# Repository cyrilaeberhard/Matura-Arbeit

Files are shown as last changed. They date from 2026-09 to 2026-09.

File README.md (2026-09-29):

<div align="center">

# Kamerabasierte Steuerung einer anthropomorphen Roboterhand

**Maturaarbeit 2026 · Cyril Aeberhard**

Eine 3D-gedruckte Roboterhand, die menschliche Fingerbewegungen in Echtzeit nachbildet –
gesteuert allein über eine Laptopkamera, ohne Handschuh und ohne Sensoren am Körper.







</div>

---

## Voraussetzungen

- Laptop mit Python 3 und Kamera
- ESP32 mit MicroPython
- Roboterhand mit 6 Servos (MG90S)

## 3D-Druck

Die Teile der Hand liegen als 3MF-Dateien im Ordner [`3d/`](3d):

| Datei | Teil |
|---|---|
| `finger.3mf` | Finger mit Fingergliedern |
| `handgeruest.3mf` | Handgerüst |
| `servo-aufsatz.3mf` | Aufsatz für die Servos |
| `kabelhalter.3mf` | Kabelhalter |
| `verbindungsstuecke_14-10-6mm.3mf` | Verbindungsstücke in 14, 10 und 6 mm Länge, mit denen die Finger zusammengesetzt werden |

Gedruckt aus ABS+ (Prototypen aus PLA).

## Installation

```bash
python3 -m venv .venv
source .venv/bin/activate
pip install -r requirements.txt
```

> MediaPipe ist auf Version 1.0.0 festgelegt, weil 1.0.1 unter macOS beim Start abstürzt.

## ESP32 einrichten

`recive.py` wird auf dem ESP32 als `main.py` gespeichert und startet so nach dem Einschalten
automatisch:

```bash
mpremote cp robot_hand/config.py :config.py
mpremote cp robot_hand/recive.py :main.py
```

## Einstellungen

In [`robot_hand/config.py`](robot_hand/config.py) an den eigenen Computer anpassen:

| Einstellung | Bedeutung |
|---|---|
| `MODELL_PFAD` | Pfad zu `hand_landmarker.task` |
| `SERIAL_PORT` | USB-Anschluss des ESP32, z. B. `/dev/cu.usbserial-…` |
| `KAMERA_INDEX` | Nummer der Kamera (meist `0` oder `1`) |

## Starten

```bash
python3 robot_hand/main.py
```

Beenden mit `q`.

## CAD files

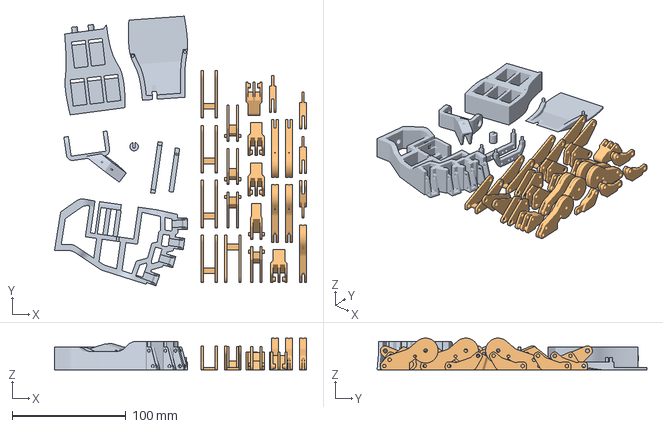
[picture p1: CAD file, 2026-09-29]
3d/finger.3mf
221.8 x 237.3 x 28.0 mm
hand gerüst final
Assembly

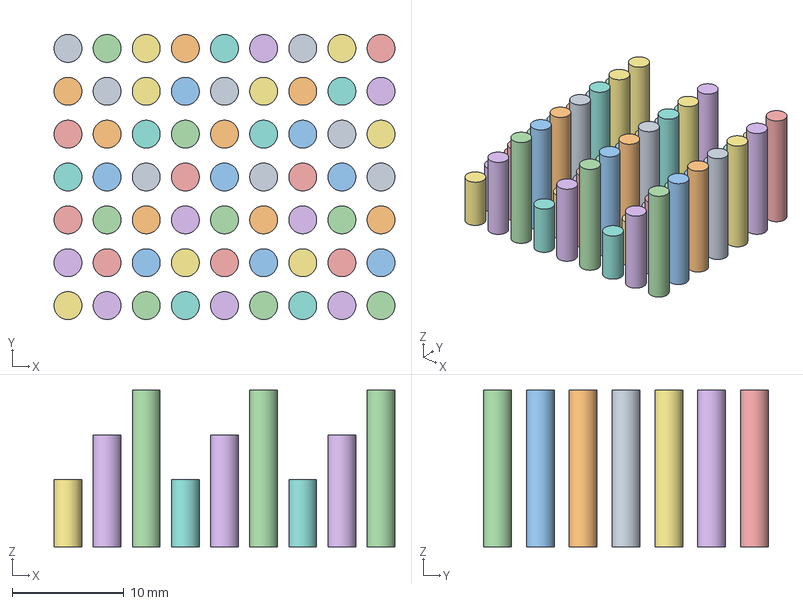
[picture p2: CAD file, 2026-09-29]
3d/verbindungsstuecke_14-10-6mm.3mf
30.5 x 25.5 x 14.0 mm
Körper1
Körper10
Körper11
Körper12
Körper13
Körper14
Körper15
Körper16
Körper17
Körper18
Körper19
Körper2
Körper20
Körper21
Körper22
Körper23
Körper24
Körper25
Körper26
Körper27
Körper28
Körper29
Körper3
Körper30
Körper31
Körper32
Körper33
Körper34
Körper35
Körper36
Körper37
Körper38
Körper39
Körper4
Körper40
Körper41
Körper42
Körper43
Körper44
Körper45
Körper46
Körper47
Körper48
Körper49
Körper5
Körper50
Körper51
Körper52
Körper53
Körper54
Körper55
Körper56
Körper57
Körper58
Körper59
Körper6
Körper60
Körper61
Körper62
Körper63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

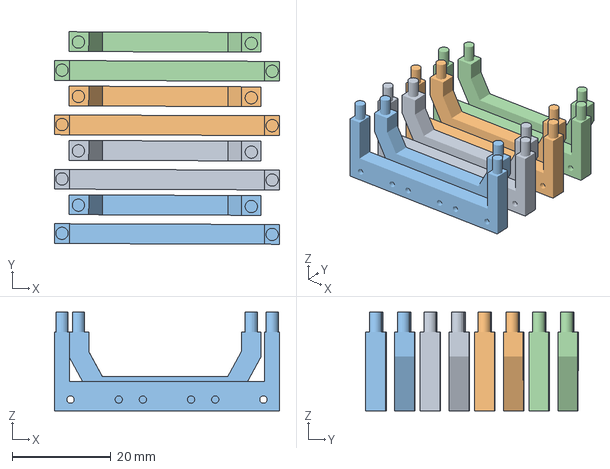
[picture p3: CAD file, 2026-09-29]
3d/handgeruest.3mf
45.5 x 43.0 x 20.0 mm
hand gerüst final x 4

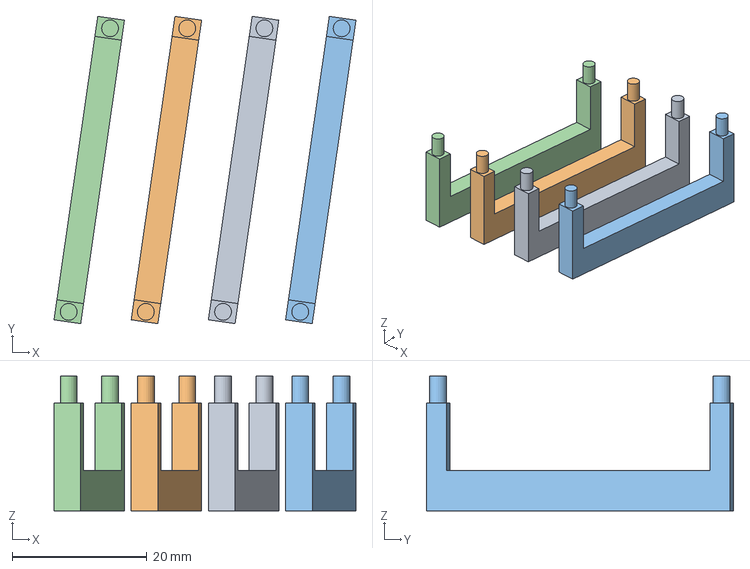
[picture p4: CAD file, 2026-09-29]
3d/kabelhalter.3mf
44.8 x 45.6 x 20.0 mm
Körper1 x 4

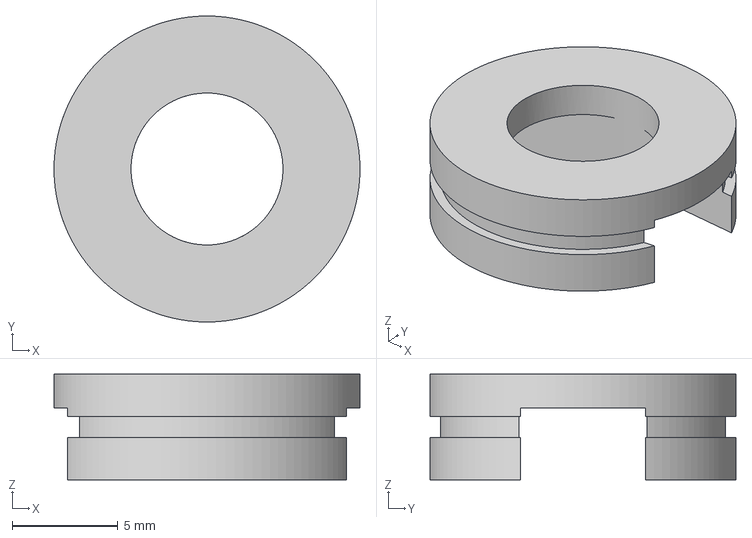
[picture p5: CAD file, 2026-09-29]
3d/servo-aufsatz.3mf
14.5 x 14.5 x 5.00 mm

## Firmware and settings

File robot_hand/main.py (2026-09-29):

# Steuert den gesamten Ablauf: Hand erkennen -> Winkel/PWM berechnen -> senden.

import cv2

import config
import hand_tracking
import calculate
import send


def main(show_camera=True):
    kamera = hand_tracking.kamera_oeffnen()
    letzte_winkel = list(config.START_WINKEL)

    try:
        while True:
            erfolgreich, kamerabild_bgr = kamera.read()
            if not erfolgreich:
                break

            # Spiegeln VOR der Erkennung, damit Landmarks und Text zur
            # gespiegelten Selfie-Ansicht passen (sonst wird auch der Text
            # spiegelverkehrt dargestellt).
            kamerabild_bgr = cv2.flip(kamerabild_bgr, 1)

            kamerabild_rgb, erkennergebnis = hand_tracking.hand_erkennen(kamerabild_bgr)

            if erkennergebnis and erkennergebnis.hand_landmarks:
                hand = erkennergebnis.hand_landmarks[0]
                neue_winkel = calculate.finger_winkel_berechnen(hand)
                letzte_winkel = calculate.glaetten(letzte_winkel, neue_winkel)

            duty_liste = calculate.winkel_liste_zu_duty_liste(letzte_winkel)
            send.duty_werte_senden(duty_liste)

            if show_camera:
                bild_mit_fingern = hand_tracking.zeichne_punkte_und_text(
                    kamerabild_rgb, erkennergebnis, letzte_winkel
                )
                bild_mit_fingern_bgr = cv2.cvtColor(bild_mit_fingern, cv2.COLOR_RGB2BGR)
                cv2.imshow("Handerkennung", bild_mit_fingern_bgr)

                if cv2.waitKey(1) & 0xFF == ord("q"):
                    break

    finally:
        kamera.release()
        cv2.destroyAllWindows()
        send.schliessen()


if __name__ == "__main__":
    main(show_camera=True)

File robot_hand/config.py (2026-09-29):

# Zentrale Einstellungen für die Handerkennung -> Servo-Steuerung.
# Diese Datei wird sowohl von den Host-Skripten (main.py, hand_tracking.py, ...)
# als auch vom ESP32 (recive.py, per mpremote/ampy hochgeladen) eingelesen.

# --- Kamera / MediaPipe ---
KAMERA_INDEX = 1
MODELL_PFAD = "/Users/cyrilaeberhard/local python/python/Maturaarbeit/hand_landmarker.task"
ANZAHL_HAENDE = 1

# --- Serielle Verbindung (Host <-> ESP32) ---
SERIAL_PORT = "/dev/cu.usbserial-11230"
BAUDRATE = 115200
SERIAL_TIMEOUT = 1

# --- Servo-Pins am ESP32 ---
# Reihenfolge: Daumen, Zeige, Mittel, Ring, Klein, Daumen-CMC (Abspreizung)
# TODO: Pin für den 6. Servo (Daumen-CMC) an die tatsächliche Verkabelung anpassen.
SERVO_PINS = [13, 12, 14, 27, 26, 25]
SERVO_FREQ = 50

# --- PWM-Duty-Grenzwerte (10-bit, passend zu machine.PWM(...).duty()) ---
DUTY_MIN = 40
DUTY_MAX = 115

# --- Finger-Landmark-Indexe im MediaPipe-Handmodell ---
FINGER_INDEXE = {
    1: {"grundgelenk": 2, "spitze": 4},    # Daumen
    2: {"grundgelenk": 5, "spitze": 8},    # Zeigefinger
    3: {"grundgelenk": 9, "spitze": 12},   # Mittelfinger
    4: {"grundgelenk": 13, "spitze": 16},  # Ringfinger
    5: {"grundgelenk": 17, "spitze": 20},  # Kleiner Finger
}
FINGER_NAMEN = ["Daumen", "Zeige", "Mittel", "Ring", "Klein", "Daumen CMC"]

# --- Kalibrierung Winkelberechnung (Zeige/Mittel/Ring/Klein, Bezug Handgelenk) ---
MIN_VERHAELTNIS = 0.7
MAX_VERHAELTNIS = 1.8
MAX_WINKEL = 120  # maximaler Servo-Winkel bei ganz ausgestrecktem Finger

# --- Kalibrierung Daumen-Beugung (Bezug: CMC-Gelenk (1) statt Handgelenk) ---
# Verhältnis dist(Spitze 4, CMC 1) / dist(Grundgelenk 2, CMC 1). Da CMC viel
# näher an den Daumengelenken liegt als das Handgelenk, ist dieser Wertebereich
# deutlich anders als MIN_VERHAELTNIS/MAX_VERHAELTNIS oben.
# Noch nicht kalibriert -- mit test.py die Rohwerte ausgeben lassen (Daumen
# einmal ganz strecken, einmal ganz einklappen) und anpassen.
DAUMEN_MIN_VERHAELTNIS = 1.8
DAUMEN_MAX_VERHAELTNIS = 2.4

# --- Kalibrierung Daumen-CMC-Gelenk (Einklappen über die Handfläche) ---
# Verhältnis (Daumenspitze<->Kleinfinger-Grundgelenk) / Handbreite.
# CMC_MIN_VERHAELTNIS: Daumen voll über die Handfläche eingeklappt (Wert mit
#   test.py ermitteln: Daumen ganz zum kleinen Finger hin einklappen).
# CMC_MAX_VERHAELTNIS: Daumen in normaler Ruheposition/gestreckt.
# Noch nicht kalibriert -- mit test.py die Rohwerte ausgeben lassen und
# anpassen.
CMC_MIN_VERHAELTNIS = 0.3
CMC_MAX_VERHAELTNIS = 1.3

# --- Glättung der Winkel zwischen zwei Frames ---
# (differenz_schwelle, faktor) -- je grösser die Bewegung, desto kleiner der
# Glättungsfaktor (schnelle Bewegung soll kaum verzögert werden)
GLAETTUNGS_STUFEN = [
    (30, 0.1),   # schnelle Bewegung
    (15, 0.3),   # mittlere Bewegung
    (5, 0.6),    # langsame Bewegung
]
GLAETTUNGS_FAKTOR_STANDARD = 0.85  # kaum Bewegung -> Zittern unterdrücken

# --- Separate Glättung für Daumen-Beugung (Index 0) und Daumen-CMC (Index 5) ---
# MediaPipe erkennt die Daumen-Landmarks deutlich unzuverlässiger als die
# übrigen Finger. Das dadurch entstehende Rauschen wird von der normalen
# Schwellenlogik oben sonst als "schnelle Bewegung" fehlinterpretiert und kaum
# geglättet -> ständiges Zittern. Deshalb hier höhere Schwellen und generell
# stärkere Faktoren: Nur wirklich grosse Sprünge gelten als echte Bewegung.
DAUMEN_GLAETTUNGS_STUFEN = [
    (45, 0.3),   # nur sehr grosse Sprünge -> etwas reaktionsschneller
    (25, 0.6),   # mittlerer Sprung -> könnte echte Bewegung sein
    (10, 0.8),   # kleiner Sprung -> vermutlich Erkennungsrauschen
]
DAUMEN_GLAETTUNGS_FAKTOR_STANDARD = 0.92  # kaum Sprung -> fast sicher Rauschen, stark glätten


START_WINKEL = [60, 60, 60, 60, 60, 60]

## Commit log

2026-09-29 feat: Roboterhand mit Webcam-Steuerung (Maturaarbeit 2026)
    Laptop-Programm (Handerkennung mit MediaPipe, Winkelberechnung, adaptive
    Glättung, serielle Übertragung), Empfänger für den ESP32, MediaPipe-Modell,
    requirements.txt und README mit Installationsanleitung.
2026-09-29 feat: 3D-Dateien der Roboterhand hinzufügen
    Finger, Handgerüst, Servo-Aufsatz, Kabelhalter und Verbindungsstücke als 3MF,
    mit klaren Dateinamen. README beschreibt, welche Datei welches Teil ist.
    [finger.3mf, handgeruest.3mf, kabelhalter.3mf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]
2026-09-29 docs: Längen der Verbindungsstücke im Dateinamen angeben
    [verbindungsstuecke_14-10-6mm.3mf]
